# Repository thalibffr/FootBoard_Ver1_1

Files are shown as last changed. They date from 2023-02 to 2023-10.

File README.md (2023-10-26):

<html lang="en">
  <head>
    <meta charset="uft-8">
    <meta name="author" content="Thalib Falih Fadhil Rabbani">
  </head>
  <body>
    <h1>ICHIRO Footboard Ver 1.1</h1>
    <p>
      Below is the design of the humanoid robot leg board to optimize the way the robot walks using the loadcell sensor.
      <br>
      <table>
        <tr>
          <td>
            <div align="center">
              3D Top View
            </div>
          </td>
          <td>
            <div align="center">
              3D Bottom View
            </div>
          </td>
          <td>
            <div align="center">
              After mounting components
            </div>
          </td>     
        </tr>
        <tr>
          <td>
            <a href="image/loadcell_v1.1 top.png.jpeg">
              <div align="center">
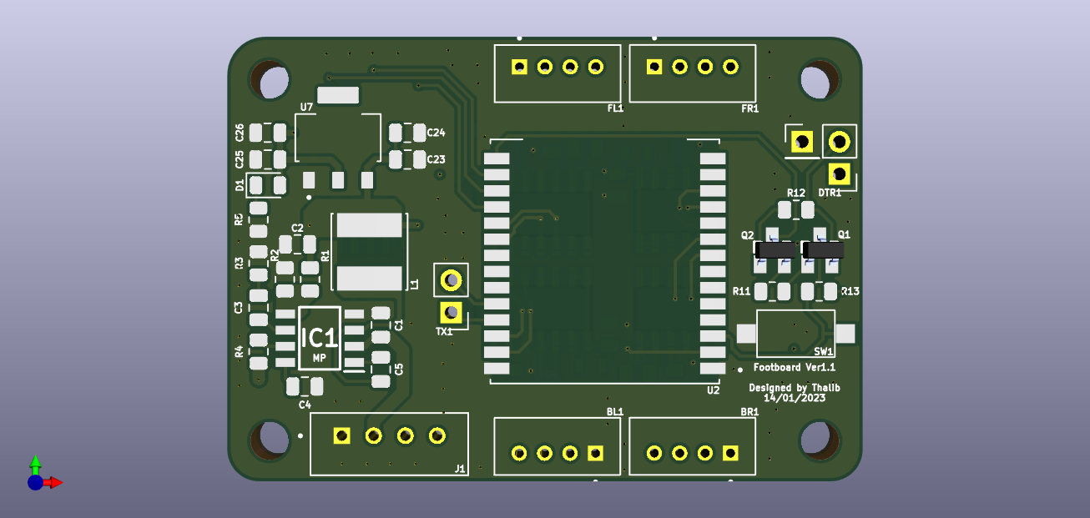
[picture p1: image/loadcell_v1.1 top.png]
                
              </div>
            </a>
          </td>
          <td>
            <div align="center">
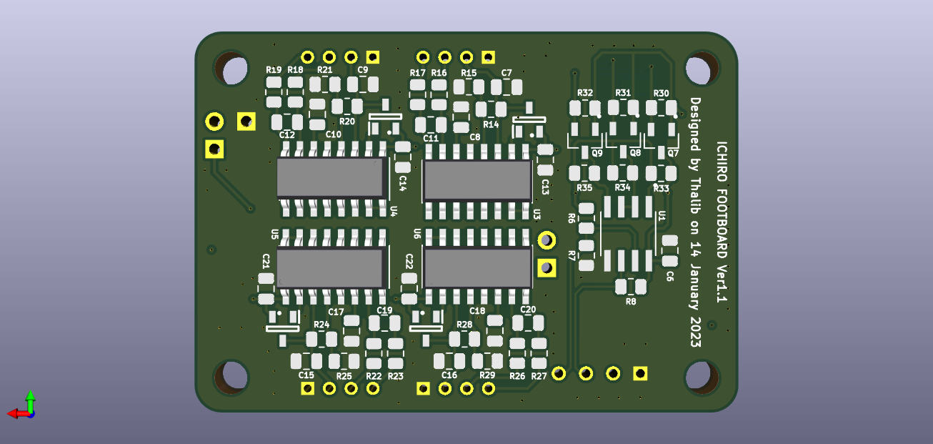
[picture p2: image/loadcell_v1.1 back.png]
              
            </div>
          </td>
          <td>
            <div align="center">
              
            </div>
          </td>
        </tr>
      </table>
    </p>
    <h2>Repository Contents</h2>
    <p>
      <ul>
        <li><a href="">Repository Contents</li>
        <li><a href="">Development</a></li>
        <li><a href="">Contact</a></li>
      </ul>
    </p>
    <h2>Development</h2>
    <p>
      <h3>BOM</h3>
    </p>
    <table>
    <tr>
      <td>ID</td>
      <td>Designator</td>
      <td>Footprint</td>
      <td>Quantity</td>
      <td>Supplier</td>
    </tr>
    <tr>
      <td>1</td>
      <td>R4</td>
      <td>R_0805_2012Metric</td>
      <td>1</td>
      <td></td>
    </tr>
    <tr>
      <td>2</td>
      <td>H4,H2,H1,H3</td>
      <td>MountingHole_3mm</td>
      <td>4</td>
      <td></td>
    </tr>
    <tr>
      <td>3</td>
      <td>R12,R11,R13,R2</td>
      <td>R_0805_2012Metric</td>
      <td>4</td>
      <td></td>
    </tr>
    <tr>
      <td>4</td>
      <td>C4,C6,C5</td>
      <td>C_0805_2012Metric</td>
      <td>3</td>
      <td></td>
    </tr>
    <tr>
      <td>5</td>
      <td>J8</td>
      <td>PinHeader_1x01_P2.54mm_Vertical</td>
      <td>1</td>
      <td></td>
    </tr>
    <tr>
      <td>6</td>
      <td>FR,BR,FL,BL</td>
      <td>JST_B4B-PH-K-S(LF)(SN)</td>
      <td>4</td>
      <td></td>
    </tr>
    </table>
    <h2>Contact</h2>
    <p>
      If you have any question feel free to contact <a href="mailto:thalibfalih@gmail.com">thalibfalih@gmail.com</a> to ask it, or open an issue on this repository.
    </p>
  </body>
</html>

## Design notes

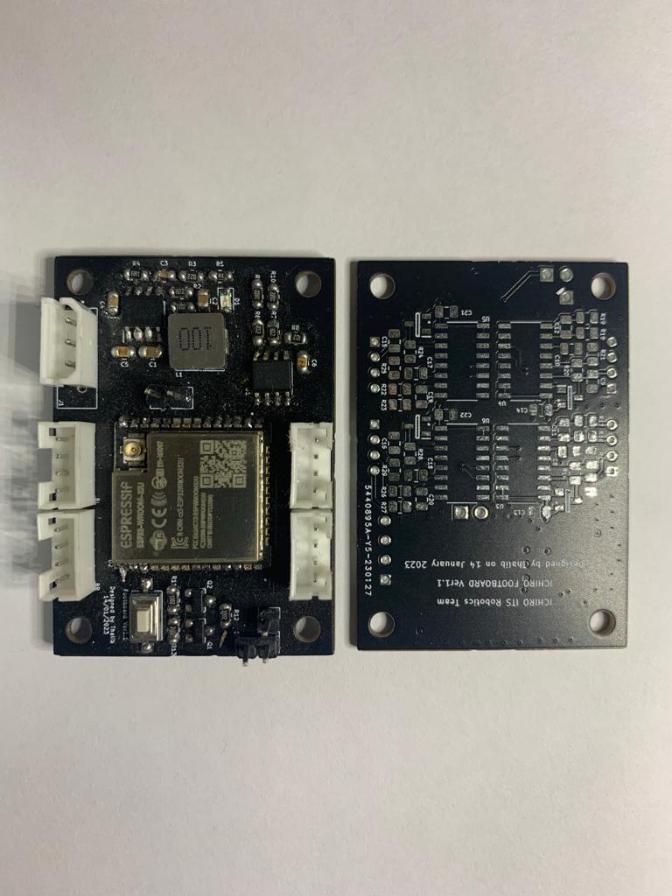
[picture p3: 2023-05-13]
image/Footboard v1-1.jpeg

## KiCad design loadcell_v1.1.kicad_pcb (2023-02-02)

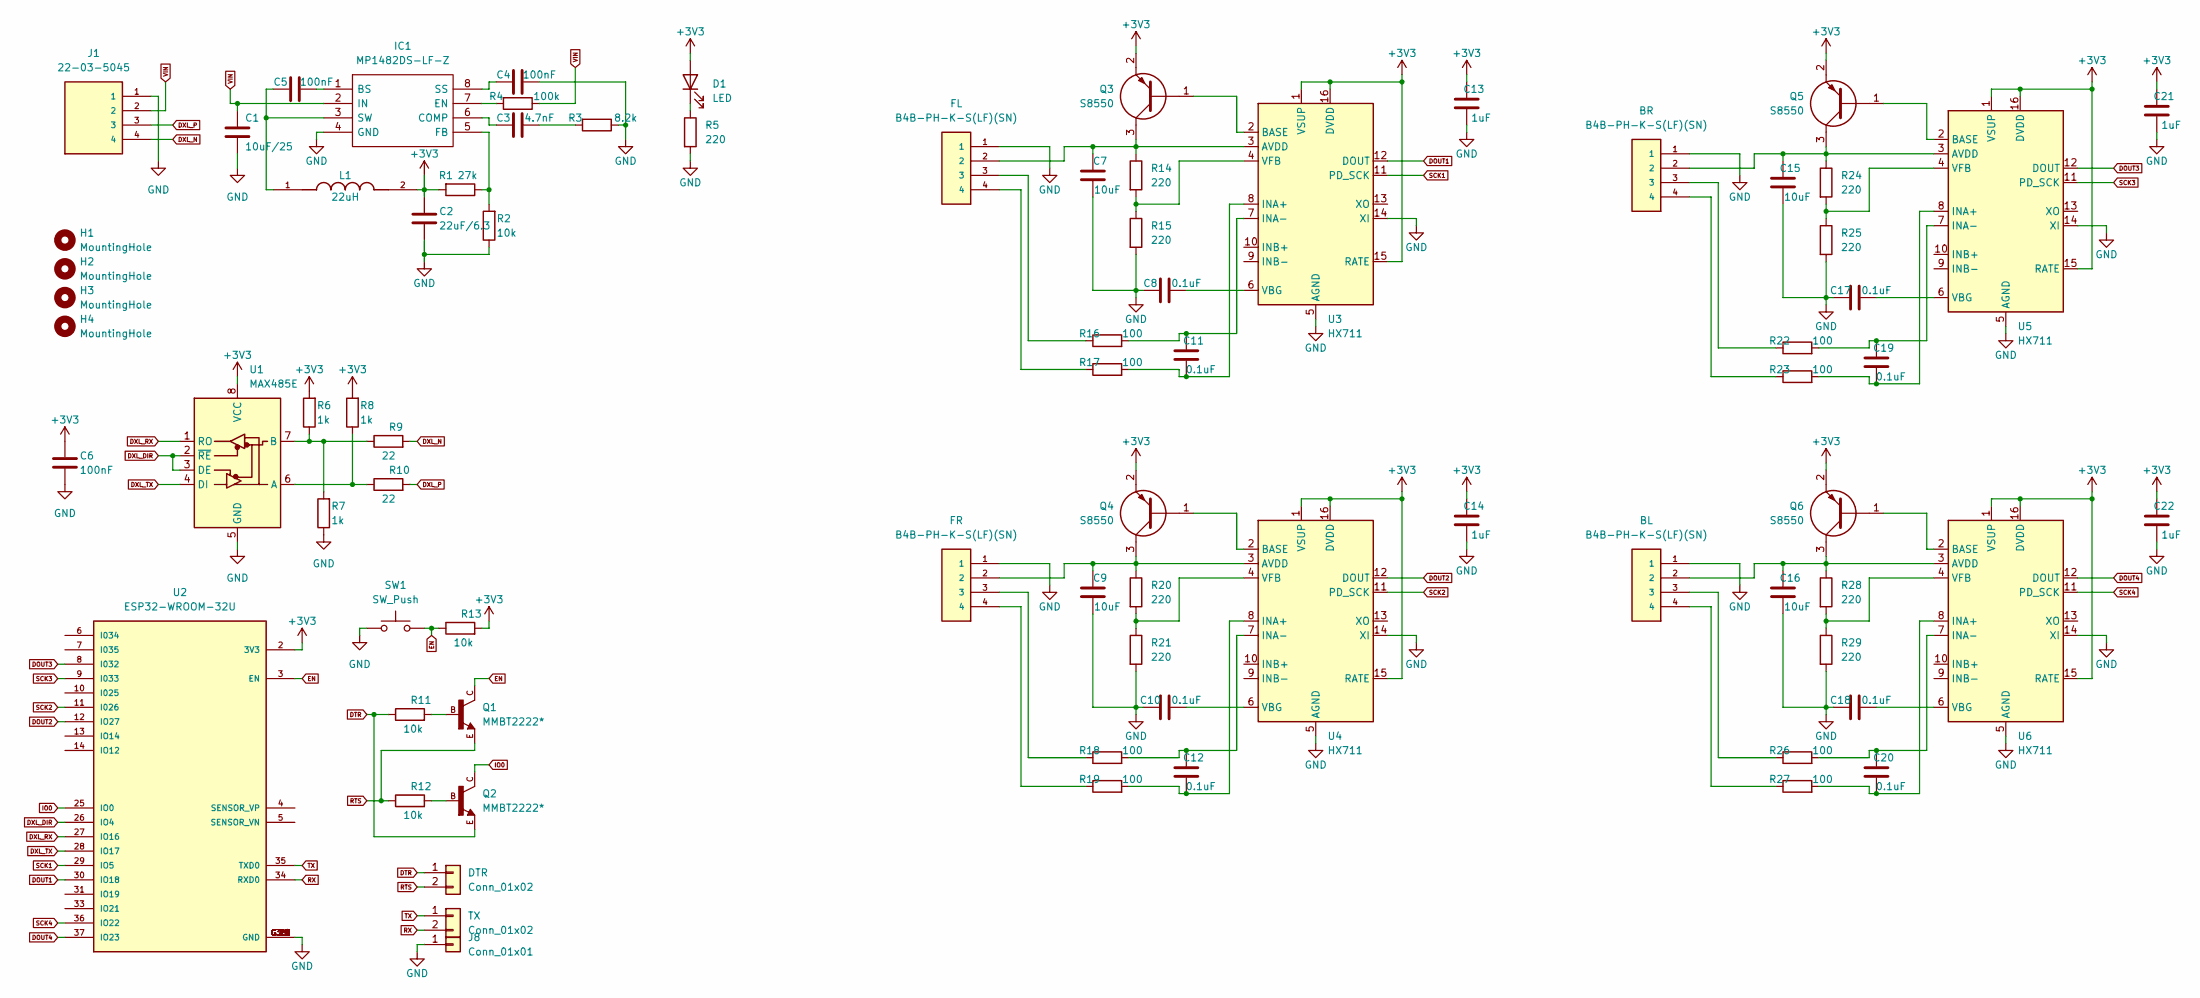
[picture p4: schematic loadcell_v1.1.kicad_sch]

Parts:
BL: B4B-PH-K-S(LF)(SN); JST_B4B-PH-K-S(LF)(SN)
BR: B4B-PH-K-S(LF)(SN); JST_B4B-PH-K-S(LF)(SN)
C1: 10uF/25; C_0805_2012Metric
C2: 22uF/6.3; C_0805_2012Metric
C3: 4.7nF; C_0805_2012Metric
C4, C5, C6: 100nF; C_0805_2012Metric
C7, C9, C15, C16: 10uF; C_0805_2012Metric
C8, C10, C11, C12, C17, C18, C19, C20: 0.1uF; C_0805_2012Metric
C13, C14, C21, C22: 1uF; C_0805_2012Metric
D1: LED; LED_0805_2012Metric
DTR: Conn_01x02; PinHeader_1x02_P2.54mm_Vertical
FL: B4B-PH-K-S(LF)(SN); JST_B4B-PH-K-S(LF)(SN)
FR: B4B-PH-K-S(LF)(SN); JST_B4B-PH-K-S(LF)(SN)
H1, H2, H3, H4: MountingHole; MountingHole_3mm
IC1: MP1482DS-LF-Z; SOIC127P600X175-8N; Manufacturer_Part_Number MP1482DS-LF-Z; Mouser Part Number 946-MP1482DSLFZ
J1: 22-03-5045; MOLEX_22-03-5045; PARTREV B
J8: Conn_01x01; PinHeader_1x01_P2.54mm_Vertical
L1: 22uH; IND_VLS6045EX-3R3N; PARTREV N/A
Q1, Q2: MMBT2222*; SOT23-BEC
Q3, Q4, Q5, Q6: S8550; SOT95P240X115-3N; Manufacturer_Part_Number S8550
R1: 27k; R_0805_2012Metric
R2, R11, R12, R13: 10k; R_0805_2012Metric
R3: 8.2k; R_0805_2012Metric
R4: 100k; R_0805_2012Metric
R5, R14, R15, R20, R21, R24, R25, R28, R29: 220; R_0805_2012Metric
R6, R7, R8: 1k; R_0805_2012Metric
R9, R10: 22; R_0805_2012Metric
R16, R17, R18, R19, R22, R23, R26, R27: 100; R_0805_2012Metric
SW1: SW_Push; SW_SPST_CK_RS282G05A3
TX: Conn_01x02; PinHeader_1x02_P2.54mm_Vertical
U1: MAX485E; SOIC127P600X175-8N
U2: ESP32-WROOM-32U; XCVR_ESP32-WROOM-32U; PARTREV V1.9
U3, U4, U5, U6: HX711; SOP127P600X180-16N

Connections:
+3V3: C2.2, C6.2, C13.2, C14.2, C21.2, C22.2, D1.2 (A), L1.2, Q3.2, Q4.2, Q5.2, Q6.2, R1.2, R6.2, R8.2, R13.2, U1.8 (VCC), U2.2 (3V3), U3.1 (VSUP), U3.15 (RATE), U3.16 (DVDD), U4.1 (VSUP), U4.15 (RATE), U4.16 (DVDD), U5.1 (VSUP), U5.15 (RATE), U5.16 (DVDD), U6.1 (VSUP), U6.15 (RATE), U6.16 (DVDD)
DOUT1: U2.30 (IO18), U3.12 (DOUT)
DOUT2: U2.12 (IO27), U4.12 (DOUT)
DOUT3: U2.8 (I032), U5.12 (DOUT)
DOUT4: U2.37 (IO23), U6.12 (DOUT)
DTR: DTR.1, Q2.E, R11.1
DXL_DIR: U1.2 (~RE), U1.3 (DE), U2.26 (IO4)
DXL_N: J1.4, R9.2
DXL_P: J1.3, R10.2
DXL_RX: U1.1 (RO), U2.27 (IO16)
DXL_TX: U1.4 (DI), U2.28 (IO17)
EN: Q1.C, R13.1, SW1.2, U2.3 (EN)
GND: BL.1, BR.1, C1.2, C2.1, C4.1, C6.1, C7.1, C8.2, C9.1, C10.2, C13.1, C14.1, C15.1, C16.1, C17.2, C18.2, C21.1, C22.1, FL.1, FR.1, IC1.4 (GND), J1.1, J8.1, R2.1, R3.1, R5.2, R7.1, R15.2, R21.2, R25.2, R29.2, SW1.1, U1.5 (GND), U2.1 (GND), U2.38 (GND), U2.G.11 (GND), U2.G.12 (GND), U2.G.13 (GND), U2.G.14 (GND), U2.G.15 (GND), U2.G.16 (GND), U2.G.17 (GND), U2.G.18 (GND), U2.G.19 (GND), U2.G.20 (GND), U2.G.21 (GND), U2.G.22 (GND), U3.5 (AGND), U3.14 (XI), U4.5 (AGND), U4.14 (XI), U5.5 (AGND), U5.14 (XI), U6.5 (AGND), U6.14 (XI)
IO0: Q2.C, U2.25 (IO0)
unnamed: C3.1, R3.2
unnamed: C3.2, IC1.6 (COMP)
unnamed: C4.2, IC1.8 (SS)
unnamed: C5.1, IC1.1 (BS)
unnamed: C5.2, IC1.3 (SW), L1.1
unnamed: C7.2, FL.2, Q3.3, R14.1, U3.3 (AVDD)
unnamed: C8.1, U3.6 (VBG)
unnamed: C9.2, FR.2, Q4.3, R20.1, U4.3 (AVDD)
unnamed: C10.1, U4.6 (VBG)
unnamed: C11.1, R17.2, U3.8 (INA+)
unnamed: C11.2, R16.2, U3.7 (INA-)
unnamed: C12.1, R19.2, U4.8 (INA+)
unnamed: C12.2, R18.2, U4.7 (INA-)
unnamed: BR.2, C15.2, Q5.3, R24.1, U5.3 (AVDD)
unnamed: BL.2, C16.2, Q6.3, R28.1, U6.3 (AVDD)
unnamed: C17.1, U5.6 (VBG)
unnamed: C18.1, U6.6 (VBG)
unnamed: C19.1, R23.2, U5.8 (INA+)
unnamed: C19.2, R22.2, U5.7 (INA-)
unnamed: C20.1, R27.2, U6.8 (INA+)
unnamed: C20.2, R26.2, U6.7 (INA-)
unnamed: D1.1 (K), R5.1
unnamed: IC1.5 (FB), R1.1, R2.2
unnamed: IC1.7 (EN), R4.2
unnamed: FL.3, R16.1
unnamed: FL.4, R17.1
unnamed: FR.3, R18.1
unnamed: FR.4, R19.1
unnamed: BR.3, R22.1
unnamed: BR.4, R23.1
unnamed: BL.3, R26.1
unnamed: BL.4, R27.1
unnamed: Q1.B, R11.2
unnamed: Q2.B, R12.2
unnamed: Q3.1, U3.2 (BASE)
unnamed: Q4.1, U4.2 (BASE)
unnamed: Q5.1, U5.2 (BASE)
unnamed: Q6.1, U6.2 (BASE)
unnamed: R6.1, R7.2, R9.1, U1.7 (B)
unnamed: R8.1, R10.1, U1.6 (A)
unnamed: R14.2, R15.1, U3.4 (VFB)
unnamed: R20.2, R21.1, U4.4 (VFB)
unnamed: R24.2, R25.1, U5.4 (VFB)
unnamed: R28.2, R29.1, U6.4 (VFB)
RTS: DTR.2, Q1.E, R12.1
RX: TX.2, U2.34 (RXD0)
SCK1: U2.29 (IO5), U3.11 (PD_SCK)
SCK2: U2.11 (I026), U4.11 (PD_SCK)
SCK3: U2.9 (I033), U5.11 (PD_SCK)
SCK4: U2.36 (IO22), U6.11 (PD_SCK)
TX: TX.1, U2.35 (TXD0)
VIN: C1.1, IC1.2 (IN), J1.2, R4.1

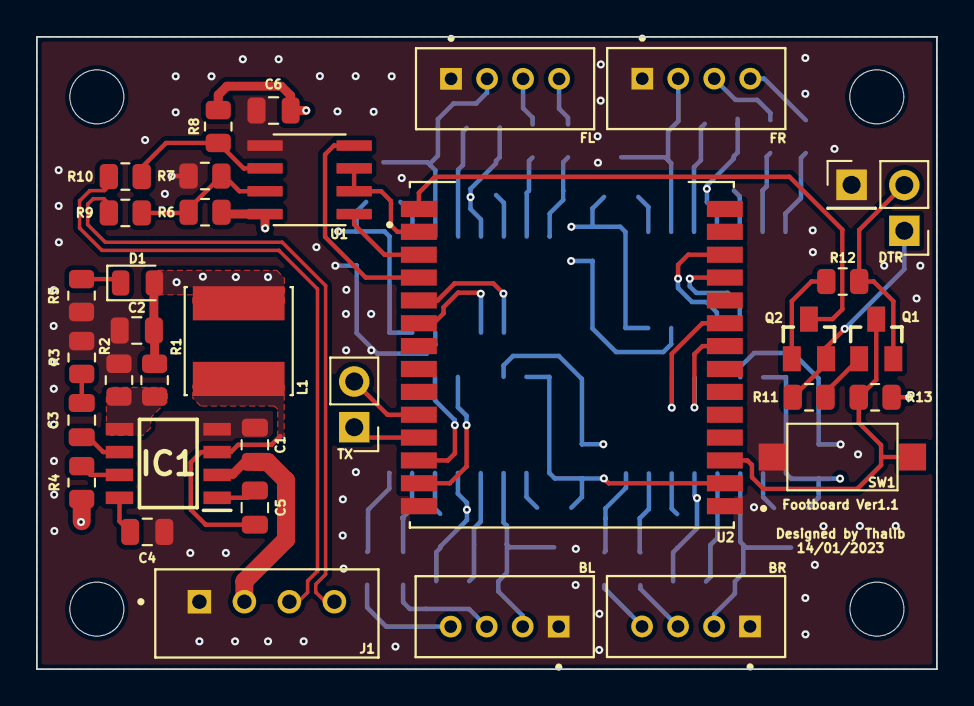
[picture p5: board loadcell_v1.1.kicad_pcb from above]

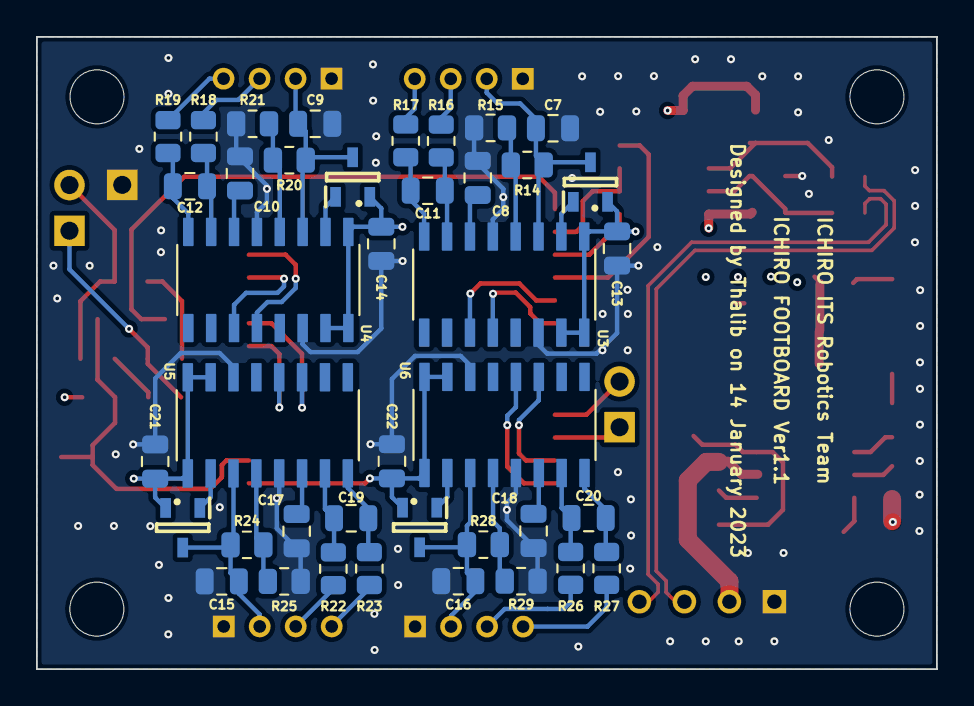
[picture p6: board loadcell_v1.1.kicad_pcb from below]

Board: 4 copper layers, 50.0 x 35.1 mm, 79 parts (40 on the bottom side), 66 nets.

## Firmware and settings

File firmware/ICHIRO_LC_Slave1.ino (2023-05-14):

/*******************************************************************************
  Copyright 2016 ROBOTIS CO., LTD.

  Licensed under the Apache License, Version 2.0 (the "License");
  you may not use this file except in compliance with the License.
  You may obtain a copy of the License at

      http://www.apache.org/licenses/LICENSE-2.0

  Unless required by applicable law or agreed to in writing, software
  distributed under the License is distributed on an "AS IS" BASIS,
  WITHOUT WARRANTIES OR CONDITIONS OF ANY KIND, either express or implied.
  See the License for the specific language governing permissions and
  limitations under the License.
*******************************************************************************/

#include <Dynamixel2Arduino.h>
#include "HX711.h"

#define DXL_SERIAL   Serial2
#define DEBUG_SERIAL Serial
const uint8_t DXL_DIR_PIN = 4;

HX711 cell1, cell2, cell3, cell4;


// Create a port object for DYNAMIXEL communication.
// The list of available classes is as follows.
// 1) DYNAMIXEL::SerialPortHandler     (HardwareSerial only)
//     -note: If you do not want to use half duplex communication, do not enter the second parameter.
// 2) DYNAMIXEL::USBSerialPortHandler  (Only USB port on each board)
DYNAMIXEL::SerialPortHandler dxl_port(DXL_SERIAL, DXL_DIR_PIN);

// Create a Slave object to communicate with the master.
const float DXL_PROTOCOL_VER_1_0 = 1.0;
const float DXL_PROTOCOL_VER_2_0 = 2.0;
const uint16_t DXL_MODEL_NUM = 0x0140; // Modify it to what you want.
DYNAMIXEL::Slave dxl(dxl_port, DXL_MODEL_NUM);

// Declare the address of the Slave control item you want
// to register and the variable (size is also important)
// to store its data.

//uint16_t ADDR_LCQ1 = 42;
//uint16_t ADDR_LCQ2 = 44;
//uint16_t ADDR_LCQ3 = 46;
//uint16_t ADDR_LCQ4 = 48;

uint16_t ADDR_SUM_LC = 50;

// note: 'int' is not supported because its size varies by system architecture.p
int q1;
int q2;
int q3;
int q4;

uint16_t s;

//This namespace is required to use Control table item names
using namespace ControlTableItem;

void setup() {
  // put your setup code here, to run once:
  DEBUG_SERIAL.begin(115200);
//  DEBUG_SERIAL.println("OKE");

  cell1.begin(18, 5);
  cell2.begin(27, 26);
  cell3.begin(32, 33);
  cell4.begin(14, 12);

  // Speed setting for communication (not necessary for USB)
  dxl_port.begin(1000000);

  dxl.setPortProtocolVersion(DXL_PROTOCOL_VER_1_0);
  dxl.setFirmwareVersion(1);
  dxl.setID(25);

  // Add control items.
  // Input the address(p1) and the variable(p2) to write/read the data as parameters.
//  dxl.addControlItem(ADDR_LCQ1, q1);
//  dxl.addControlItem(ADDR_LCQ2, q2);
//  dxl.addControlItem(ADDR_LCQ3, q3);
//  dxl.addControlItem(ADDR_LCQ4, q4);

  dxl.addControlItem(ADDR_SUM_LC, s);
}

void loop() {
  // put your main code here, to run repeatedly:

//   If there is a packet from the master, process it.
  if (dxl.processPacket() == false) {
    DEBUG_SERIAL.print("Last lib err code: ");
    DEBUG_SERIAL.print(dxl.getLastLibErrCode());
    DEBUG_SERIAL.print(", ");
    DEBUG_SERIAL.print("Last status packet err code: ");
    DEBUG_SERIAL.println(dxl.getLastStatusPacketError());
    DEBUG_SERIAL.println();
  }
  
  q1 = cell1.read()/400;
  q2 = 1400;
  q3 = 1400;
  q4 = 1400;

//  q1 = random(1200, 1400);
//  q2 = random(1000, 1200);
//  q3 = random(1000, 1200);
//  q4 = random(1000, 1200);
  
  s = (q1 + q2 + q3 + q4)/4;
  
//
    DEBUG_SERIAL.print(q1); DEBUG_SERIAL.print("\t"); //DEBUG_SERIAL.print(q2);  DEBUG_SERIAL.print("\t");
//  DEBUG_SERIAL.print(q3); DEBUG_SERIAL.print("\t"); DEBUG_SERIAL.print(q4);  DEBUG_SERIAL.print("\t");
//  DEBUG_SERIAL.print(s);  DEBUG_SERIAL.print("\t");
 DEBUG_SERIAL.println("");
}

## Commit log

2023-02-02 add sch & brd file
    [loadcell_v1.1.kicad_pcb, loadcell_v1.1.kicad_sch]
2023-10-26 Update README.md BOM
